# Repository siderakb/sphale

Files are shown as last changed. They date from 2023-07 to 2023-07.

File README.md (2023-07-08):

# Sphale



Pro Micro/Proton C compatible [STM32F303CC](https://www.st.com/en/microcontrollers-microprocessors/stm32f303cc.html) board, specialized design for [QMK](https://github.com/qmk/qmk_firmware) keyboards.

> ***Sphale***rite  

## Board Characteristics

-  Copper layer count: 2
-  Board thickness: 1.6 mm
-  Board overall dimensions: 17.78 x 33.02 mm (0.7 x 1.3 inch)
-  Min track/spacing: 0.13 mm / 0.13 mm
-  Min hole diameter: 0.3 mm
-  Castellated pads: No
-  Edge card connectors: No
-  Plated board edge: No

## Disclaimer

These files are provided without warranty of any kind.  
Including but not limited to manufacturing, assembly, procurement and use at your own risk.  
It is recommended to check yourself before use.

For the full statement, please see [LICENSE](./LICENSE).

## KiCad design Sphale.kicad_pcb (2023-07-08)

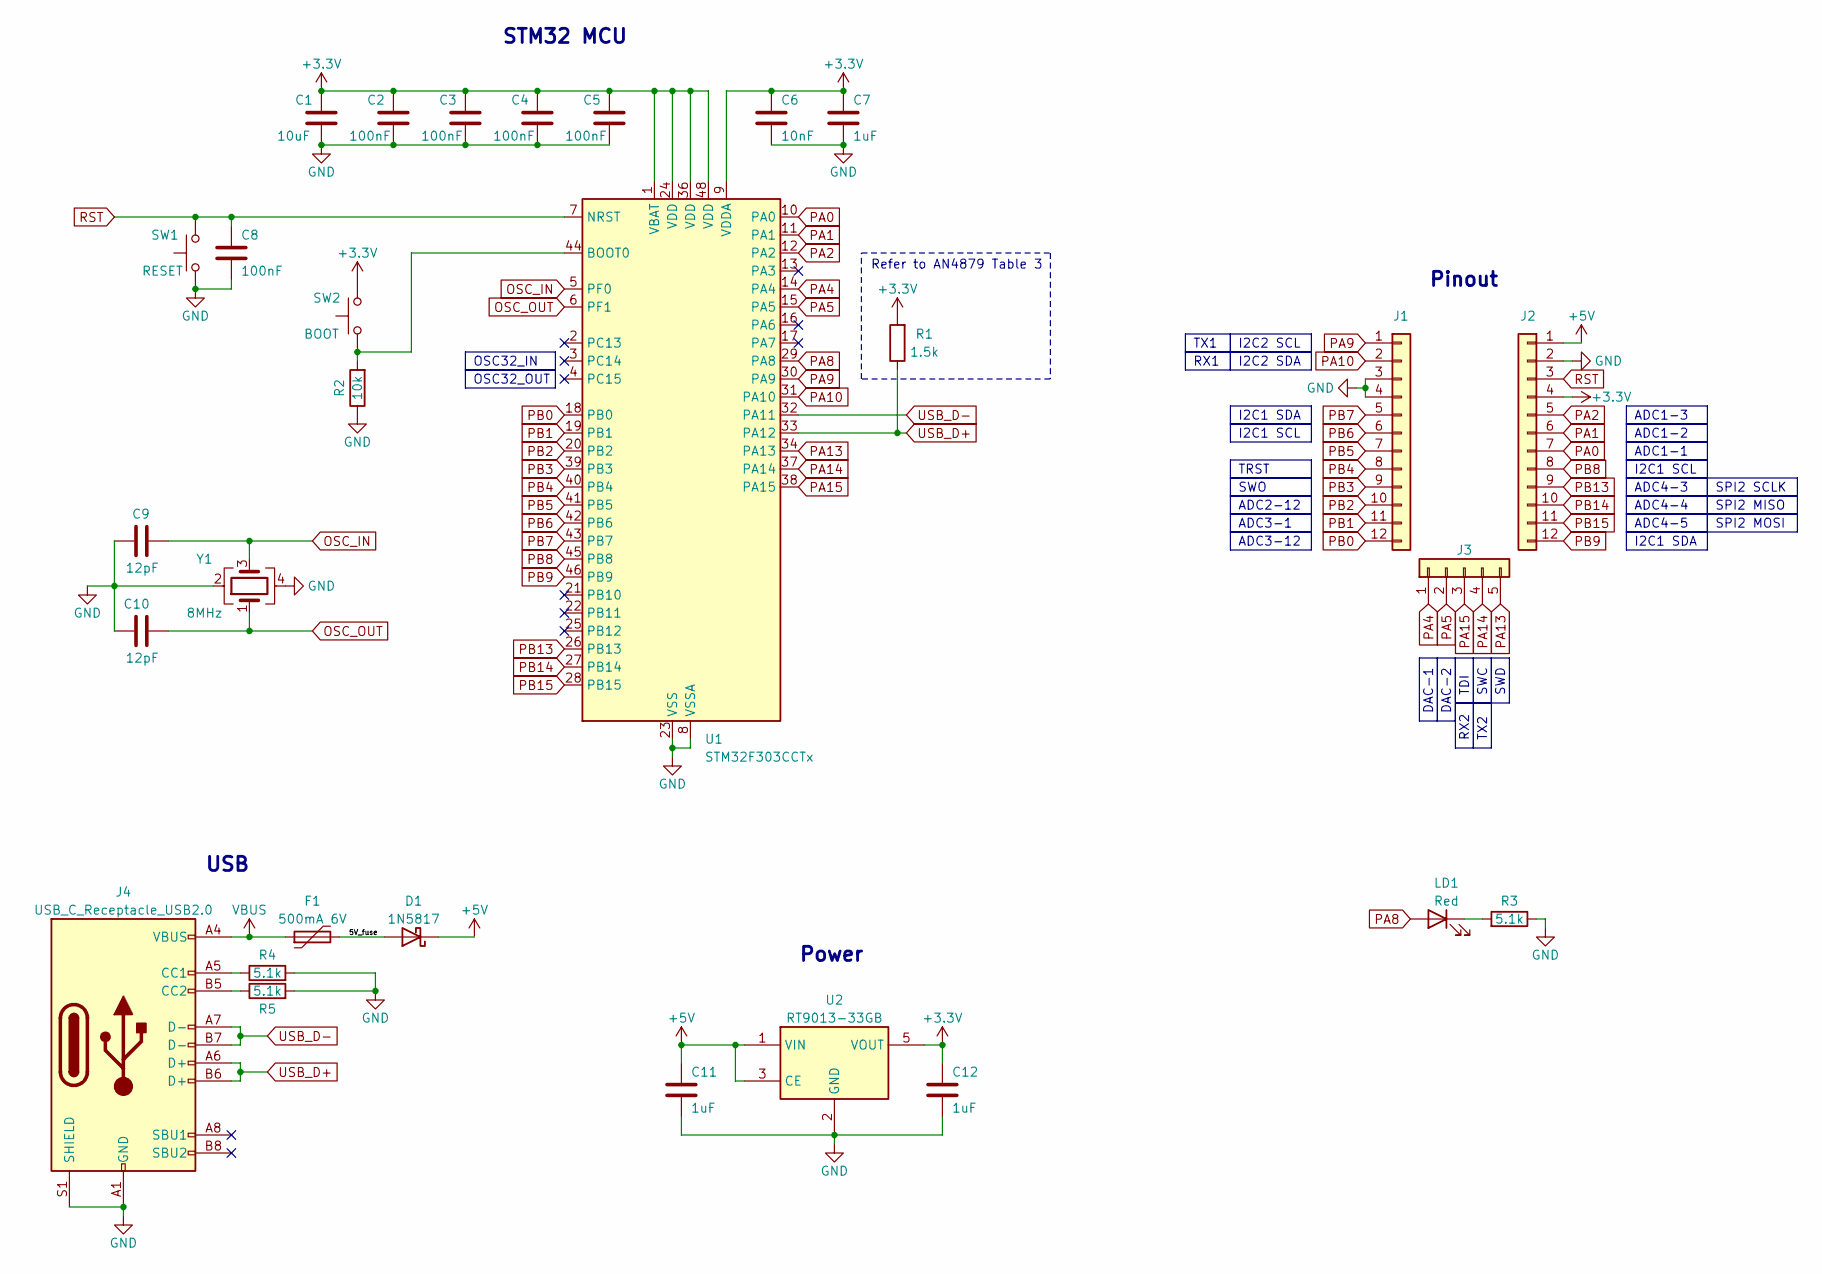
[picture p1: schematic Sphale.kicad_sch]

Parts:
C1: 10uF; C_0402_1005Metric; MFR. Part# CL05A106MQ5NUNC; LCSC C15525
C2, C3, C4, C5, C8: 100nF; C_0402_1005Metric; MFR. Part# CL05B104KO5NNNC; LCSC C1525
C6: 10nF; C_0402_1005Metric; MFR. Part# CL05B103KB5NNNC; LCSC C15195
C7, C11, C12: 1uF; C_0402_1005Metric; MFR. Part# CL05A105KA5NQNC; LCSC C52923
C9, C10: 12pF; C_0402_1005Metric; MFR. Part# 0402CG120J500NT; LCSC C1547
D1: 1N5817; D_SOD-323_HandSoldering; MFR. Part# B5817WS; LCSC C123899
F1: 500mA 6V; Fuse_0805_2012Metric; MFR. Part# SMD0805B050TF; LCSC C269104
J1, J2: Conn_01x12; PinHeader_1x12_P2.54mm_Vertical
J3: Conn_01x05; PinHeader_1x05_P2.54mm_Vertical
J4: USB_C_Receptacle_USB2.0; USB_C_Receptacle_HRO_TYPE-C-31-M-12; MFR. Part# TYPE-C-31-M-12; LCSC C165948
LD1: Red; LED_0603_1608Metric; MFR. Part# KT-0603R; LCSC C2286
R1: 1.5k; R_0402_1005Metric; MFR. Part# ARG02BTC1501; LCSC C2984410
R2: 10k; R_0402_1005Metric; MFR. Part# 0402WGF1002TCE; LCSC C25744
R3, R4, R5: 5.1k; R_0402_1005Metric; MFR. Part# 0402WGF5101TCE; LCSC C25905
SW1: RESET; SW_SPST_B3U-1000P; MFR. Part# TS-1064S-A1B2-D4; LCSC C498294
SW2: BOOT; SW_SPST_B3U-1000P; MFR. Part# TS-1064S-A1B2-D4; LCSC C498294
U1: STM32F303CCTx; LQFP-48_7x7mm_P0.5mm; MFR. Part# STM32F303CCT6; LCSC C81523
U2: RT9013-33GB; SOT-23-5; MFR. Part# TPRT9013-33GB; LCSC C587158
Y1: 8MHz; Crystal_SMD_3225-4Pin_3.2x2.5mm; MFR. Part# X32258MSB4SI; LCSC C2682774

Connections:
+3.3V: C1.1, C2.1, C3.1, C4.1, C5.1, C6.1, C7.1, C12.1, J2.4, R1.2, SW2.2, U1.1 (VBAT), U1.9 (VDDA), U1.24 (VDD), U1.36 (VDD), U1.48 (VDD), U2.5 (VOUT)
+5V: C11.1, D1.1 (K), J2.1, U2.1 (VIN), U2.3 (CE)
/5V_fuse: D1.2 (A), F1.2
GND: C1.2, C2.2, C3.2, C4.2, C5.2, C6.2, C7.2, C8.2, C9.1, C10.1, C11.2, C12.2, J1.3, J1.4, J2.2, J4.A1 (GND), J4.A12 (GND), J4.B1 (GND), J4.B12 (GND), J4.S1 (SHIELD), R2.1, R3.1, R4.2, R5.2, SW1.1, U1.8 (VSSA), U1.23 (VSS), U1.35 (VSS), U1.47 (VSS), U2.2 (GND), Y1.2, Y1.4
unnamed: J4.A5 (CC1), R4.1
unnamed: J4.B5 (CC2), R5.1
unnamed: LD1.1 (K), R3.2
unnamed: R2.2, SW2.1, U1.44 (BOOT0)
OSC_IN: C9.2, U1.5 (PF0), Y1.3
OSC_OUT: C10.2, U1.6 (PF1), Y1.1
PA0: J2.7, U1.10 (PA0)
PA1: J2.6, U1.11 (PA1)
PA2: J2.5, U1.12 (PA2)
PA4: J3.1, U1.14 (PA4)
PA5: J3.2, U1.15 (PA5)
PA8: LD1.2 (A), U1.29 (PA8)
PA9: J1.1, U1.30 (PA9)
PA10: J1.2, U1.31 (PA10)
PA13: J3.5, U1.34 (PA13)
PA14: J3.4, U1.37 (PA14)
PA15: J3.3, U1.38 (PA15)
PB0: J1.12, U1.18 (PB0)
PB1: J1.11, U1.19 (PB1)
PB2: J1.10, U1.20 (PB2)
PB3: J1.9, U1.39 (PB3)
PB4: J1.8, U1.40 (PB4)
PB5: J1.7, U1.41 (PB5)
PB6: J1.6, U1.42 (PB6)
PB7: J1.5, U1.43 (PB7)
PB8: J2.8, U1.45 (PB8)
PB9: J2.12, U1.46 (PB9)
PB13: J2.9, U1.26 (PB13)
PB14: J2.10, U1.27 (PB14)
PB15: J2.11, U1.28 (PB15)
RST: C8.1, J2.3, SW1.2, U1.7 (NRST)
USB_D+: J4.A6 (D+), J4.B6 (D+), R1.1, U1.33 (PA12)
USB_D-: J4.A7 (D-), J4.B7 (D-), U1.32 (PA11)
VBUS: F1.1, J4.A4 (VBUS), J4.A9 (VBUS), J4.B4 (VBUS), J4.B9 (VBUS)

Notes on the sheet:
SWD
I2C1 SCL
ADC4-5
TX2
DAC-1
OSC32_IN
I2C1 SDA
ADC4-4
ADC4-3
SPI2 SCLK
SPI2 MISO
ADC3-1
DAC-2
OSC32_OUT
I2C2 SCL
RX2
TDI
SWC
SWO
ADC1-3
TX1
TRST
ADC1-2
SPI2 MOSI
ADC1-1
I2C2 SDA
ADC3-12
ADC2-12
RX1
USB
Power
Refer to AN4879 Table 3
STM32 MCU
Pinout

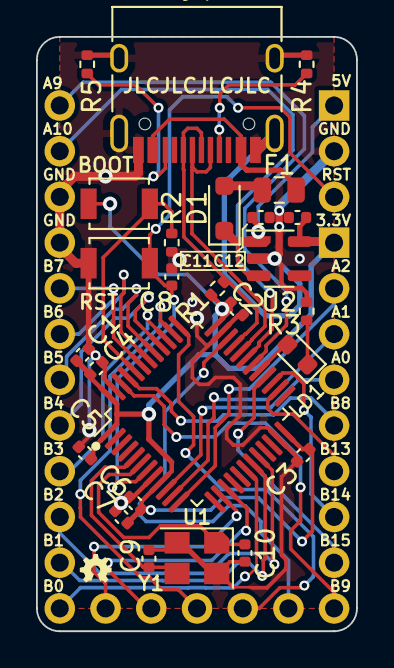
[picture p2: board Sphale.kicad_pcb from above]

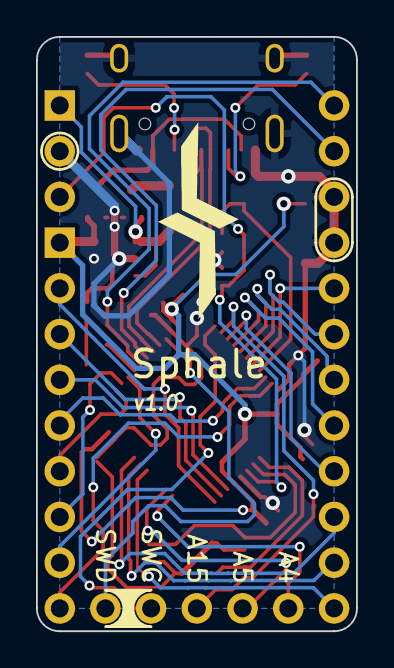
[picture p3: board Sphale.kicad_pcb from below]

Board: 2 copper layers, 17.8 x 33.0 mm, 29 parts (2 on the bottom side), 38 nets.

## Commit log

2023-06-19 Init commit
    [Sphale.kicad_pcb, Sphale.kicad_sch]
2023-07-08 Update BOM and references
    [Sphale.kicad_pcb, Sphale.kicad_sch]
